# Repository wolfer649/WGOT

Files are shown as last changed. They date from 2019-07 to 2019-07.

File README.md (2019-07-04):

# World's Greatest Oven (Appliance?) Thermometer
# Overview
This is a standalone Raspberry Pi hardware assembly project and associated software that can be used to measure, chart and record appliance temperatures over time, using a cable-attached thermocouple probe.
# Features
On the the 2.8" PiTFT capacitive touchscreen, this device will show the current temperature, with the option of an additional save/hold temperature value or even a graph of the temperature over time.
The selections are chosen by pressing associated buttons on the PiTFT screen's board and by touching the PiTFT screen.

You can also reset the timer, in case you want to start recording again – say after a false start or changing adjustment values.

It also creates a csv log file that can later be used offline, to build fancy graphs or spreadsheets for analysis purposes. Two older csv log files are saved, so that data is not lost after a reboot

Optionally, this Linux-based device can be shutdown and/or restarted at the touch of a single button, to avoid having to remove and replace the power supply connection.

There is also a handy flashing LED activity indicator, so that you can check if the software is alive: especially useful in "headless" mode.

No Internet connection is required, because all of the timing is relative and typical CPU utilization is less than 10%.

For development purposes, the software can be tested on an attached X11 HDMI screen/keyboard (or via VNC) without access to the PiTFT itself, though you definitely need the Perma-Proto Hat board with the MAX31855 board attached to make it work.
# History
Proto22 was the first beta version.

Proto25 included the following changes.
- Fix the problem of the activity LED being left on after the programme exits
- Save the last two csv log files when the programme is restarted 
- Change the chart line's colour from red to blue if the current temperature is at or below freezing

Proto26 added the following changes.
- Fix the problem with the csv log file not having a time-zero entry
- Documentation was updated as well.

Proto28 added the following changes.
- Fix activity LED not being turned off after keyboard exit, via 'x' key on main display.
- Improve debug messages, if enabled in the code.
- Use Decimal arithmetic for Temperature Adjustment menu, to avoid odd values with binary math.
- Update documentation to show how to log stdout, stderr messages from rc.local.

Proto29 added the following changes.
- Shift screens to the right, to accommodate PiTFT faceplate for Cyntech case.
- Minor fixes to comments and debug code.
# Usage
Follow the instructions in the documentation to build the hardware and to install pre-requisite software.
The following command will execute the programme.
There is also an example rc.local in the documentation that will log runtime messages.

sudo python Proto29.py

or

sudo python3 Proto29.py
# Known Bugs
The activity LED may stay on after the software exits. (Proto22 - 2019-02-24)

The csv log does not include time-zero values at startup or after restart. (Proto25 - 2019-03-08)
- Fixed in Proto26

Code to force the display to the PiTFT display no longer works with Rasbian Stretch with updates if an X11 display is available.
- It still displays OK on the PiTFT when started from rc.local.
- Looking at a workaround for this issue.

Temperature Adjustment menu can show -0.0 instead of 0.0 (Proto28 - 2019-05-01)
- This doesn't cause a problem

Forcetft variable no longer forces the display to the PiTFT if an X11 display is active on Rasbian Stretch (Proto28 - 2019-05-01)
- The PiTFT display still works when it's started from rc.local, even if an HDMI X11 display is attached.
- i.e. It is still possible to run Proto28.py in headless mode, using the PiTFT as the only display.

The activity LED may stop flashing, but the PiTFT buttons still work OK. (Proto29 - 2019-07-03)
- TBD

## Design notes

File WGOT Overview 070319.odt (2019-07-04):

# World's Greatest Oven Thermometer

(Rev 0.8: Jul 3, 2019)

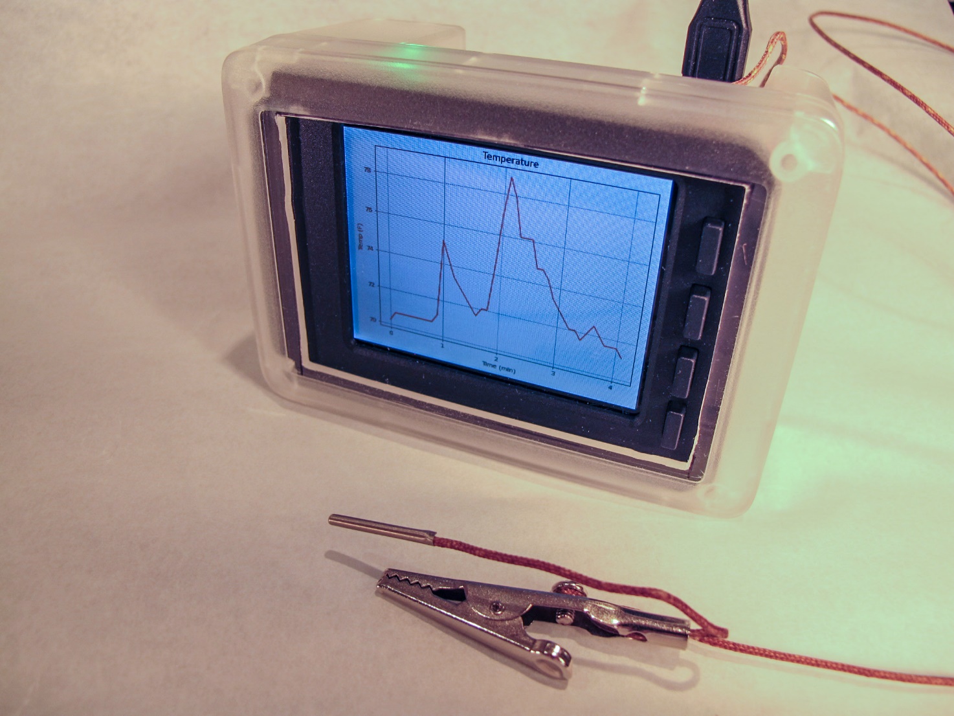
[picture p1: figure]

Note: the alligator clip is for attaching the thermocouple to an anchor point

## Features

On the the stacked 2.8" PiTFT capacitive touchscreen, this device will show the current temperature, with the option of an additional save/hold temperature value or even a graph of the temperature over time, using a cable-attached type K thermocouple probe.

The advantage of using a thermocouple is that it can measure very high and very low temperatures with good accuracy – and the Pi assembly itself doesn't have to be exposed to them.

Optionally, this Linux-based device can be shutdown and/or restarted at the touch of a single button, to avoid having to remove and replace the power supply connection.

There is also a handy flashing LED activity indicator, so that you can check if the software is alive: especially useful in "headless" mode.

No Internet connection is required, because all of the timing is relative.

It even creates a csv log file that can later be used offline, to build fancy graphs or spreadsheets for analysis purposes and typical CPU usage is below 10%. The last two csv log files are saved, so that data from a recent test isn't lost after a reboot.

For development purposes, the software can be tested on an attached X11 HDMI screen/keyboard (or via VNC) without access to the PiTFT itself, by un-commenting a single Python statement, though you definitely need the Perma-Proto Hat board with the MAX31855 board attached.

## Background

Why make an oven thermometer using a quad core, general purpose computer with a multi-user operating system? Because you can! And because of all the pieces together cost about a hundred bucks, and because all of the open source software is totally free.

When we got a new kitchen range, it didn't bake as well as the old one, so I tried a $7.99 oven thermometer – no help, since it was so very slow to respond. Then I tried a multimeter with a temperature probe, but I had to write down all of the values, over time, and graph them to a spreadsheet – too boring, time consuming and error-prone.

It was only when I cobbled together a Raspberry Pi and an Adafruit MAX31855 breakout board with a thermocouple probe, along with some copy/paste Python programming and, Matplotlib, that I uncovered the real problem. The oven's temperature was dipping down significantly from the set temperature for 10 minutes after the oven said that it was pre-heated – not good for cookies that only take 20 minutes to bake. So now we use a 20 minute pre-heat, regardless of what the oven says.

Problem solved? Well yes, except that we had friends with similar issues and it was a pain to drag my screen, keyboard, breadboard, Pi and cables over to their home and set it up.

So, in the interest of portability I built a prototype, self-contained unit that can be easily used to measure and graph oven temperatures, using a Raspberry Pi 3 B with Raspbian Stretch, an Adafruit MAX31855 thermocouple breakout board, an Adafruit 2.8" capacitive touschscreen, along with Python, Pygame and Matplotlib (amongst other open source packages.) All you'd need to carry around is the main unit and a power supply.

The following describes how it works and how it's made.

Please keep in mind that this is just a prototype, eh.

## Operation

When first powered on, the device will display a "Starting" splash screen, followed by a continuously updated time/temperature display with button labels.

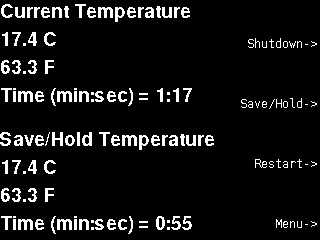
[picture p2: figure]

"Buttons" referred to below are referenced as button 1 being labelled #17 on the PiTFT board, button, 2 as #22, button 3 as #23 and button 4 as #27".

Button 1 is a software-independent OS shutdown/restart button, which will perform an orderly shutdown of the OS, when the device is active, or will reboot it if it has been shutdown. The latter saves having to disconnect and reconnect power to the Raspberry Pi to restart it after a shutdown.

The following are screenshots of the currently available display options, captured in X11 testing mode using the built-in Raspbian Stretch "scrot" command. Type "man scrot" in a terminal window to see how "scrot" works.

At any time, pressing "x" on the keyboard, or clicking "X" on the X11 window title bar will just exit the software – the current prototype debugging default.

Also, in the above display, pressing button 2 on thePiTFT (or the "h" key on the keyboard) will capture the current temperature and time as a Save/Hold Temperature and update the display.

Similarly, pressing button 3 (or "r" on the keyboard) will restart the timer and temperature capture data. A line of zero ("00") values will be written to the csv file to record this event for future analysis purposes.

Graph Display

Touching the PiTFT screen (or clicking directly on the X11 window) during the above display will switch to the following graphic display.

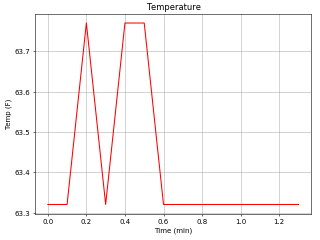
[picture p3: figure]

Axis values are automatically adjusted based on the total time period and temperature range that the graph covers, so decimal points may move or disappear and the graph line colour will change to blue if the temperature is at or below freezing.

Touching the PiTFT screen (or clicking on the window in X11 mode) while the graph is being displayed will revert to the latest active time/temperature display above.

Note that pressing button 2 (or hitting "h" on the keyboard) during the graph display will capture the current temperature and time, but will not terminate the graph display. Instead, the current time/temperature display will appear the next time the graph is touched/clicked.

Also note that the graph may appear blank after a Restart, until enough data has been recorded to show a complete graph. (i.e. After enough recording time intervals have expired.)

Menu

If you press button 4 on the PiTFT (or hit "m" on the keyboard) either display above will switch to the following main menu display. Time and temperature will still be captured during the menu display and the updated graph or temperature display will be restored when you select the Return option.

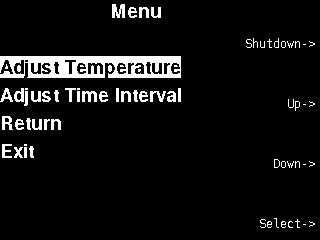
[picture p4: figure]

In menu mode, if a keyboard is available, the "u" key will simulate PiTFT button 2, to scroll the highlighting up through the options; the "d" key will simulate PiTFT button 3, to scroll down and the "s" key will simulate PiTFT button 4 to select the highlighted option. As before the "x" key, or clicking the upper-right "X" on the X11 window title bar will exit the software at any time in menu mode during testing.

The Return option will simply revert to the temperature display, while the Exit option will exit the programme completely.

Temperature Adjustment Menu

The Adjust Temperature menu allows a fixed temperature adjustment to be applied to all ongoing readings. You might use this if, for example, you notice that the temperature on the device does not match a more accurate temperature source that you have available. The value that is shown when this sub-menu appears for the first time reflects an adjustment value that is hard coded into the software.

The big assumption here is that the basic Type K thermocouple readings are linear enough within a practical usage range at home.

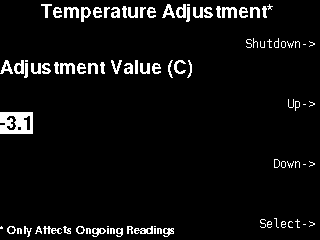
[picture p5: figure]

Up will increase the temperature adjustment by 0.1 degrees C and Down will decrease it by 0.1 degrees C within a limit of +/- 10 degrees C.

This will not affect already recorded readings - which could result in a change in the ongoing graph - until a value is Selected. In general it is a good idea to do a 'Restart' from the main temperature or graph display after making an adjustment change, to start with fresh and consistent temperature readings.

The chosen value will only take effect, once the Select button is pressed, so it is possible to undo a change by scrolling to the value that was shown when the menu initially appeared and Selecting it.

Note that adjustment value changes are not currently saved across shutdowns and so must be re-entered each time that the software is started.

Time Adjust Menu

The Time Adjustment sub-menu allows the time interval that is used for data collection (e.g. For graphing and for csv files) to be changed from a list of values that are hard-coded in the software.

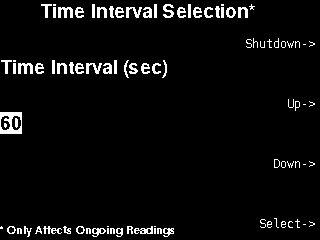
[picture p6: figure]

The chosen value will only take effect, once the Select button is pressed, so it is possible to undo a change by scrolling back to the value that was shown when the menu initially appeared. Previous data that has been recorded will not be lost unless a Restart is performed.

The list of values that is currently available is 6, 30, 60, 120, 600, 1800 and 3600 seconds, with the default being 6 seconds, so that you can watch the graph change quickly the first time you start it. The largest values may be useful for measuring things like refrigerators or outdoor temperatures.

The Up button will move through increasing values from the available values and the Down button will move through the decreasing values.

## Hardware Overview

The modestly named World's Greatest Oven Thermometer (WGOT) consists of three, stacked subassmblies.

1. A Raspberry Pi3 B bottom board
2. An Adafruit Perma-Proto Hat with MAX31855 board & connections - middle board
3. An Adafruit 2.8" PiTFT capacitive touchscreen, with buttons, on top

The following photo shows the prototype subassemblies.

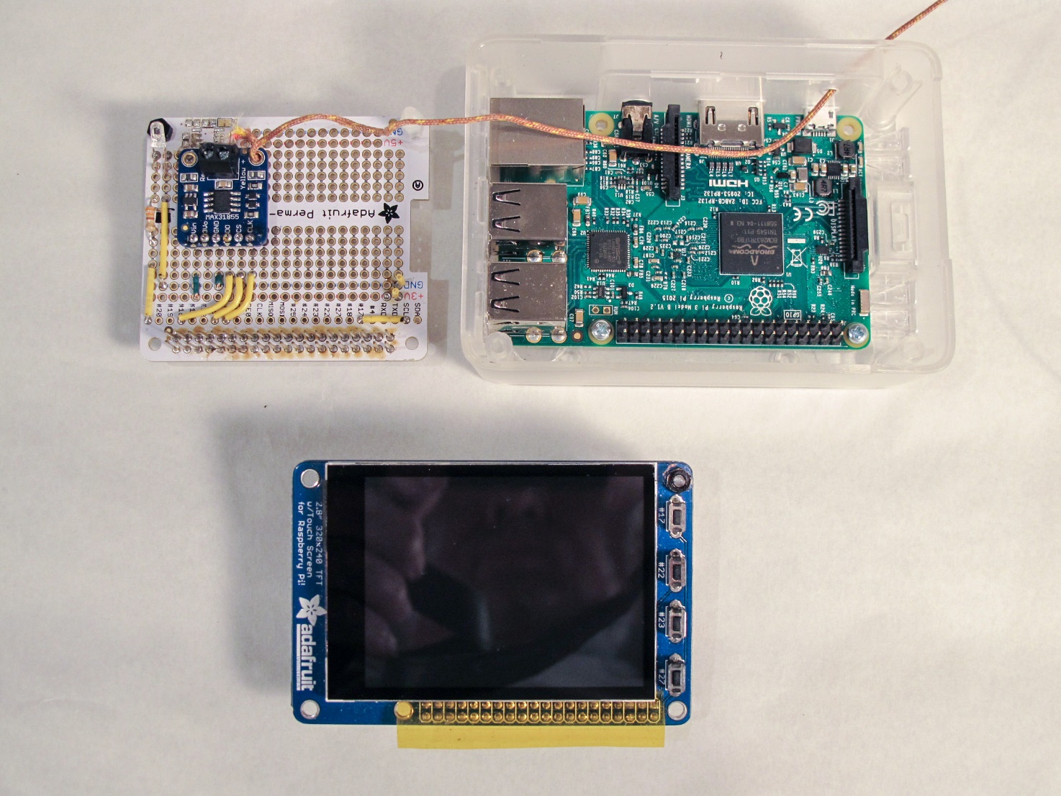
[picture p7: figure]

Note: This shows the Cyntech base case, but the Adafruit one works well for testing.

## Hardware Assembly

The following is a list of the parts required to build the prototype shown – just a starting point – using Adafruit part numbers.

Note: In Canada, most Adafruit parts and the Cyntech case are available from Elmwood Electronics - to avoid shipping delays and customs, eh.

Sub-assy | Description | Adafruit Part #
CPU
| Raspberry Pi 3 B | 3055
| Power Supply | 1995
| 32 GB micro SD card
Sensor
| Thermocouple (S/S tip) | 3245
| MAX31855 board | 269
| Perma-Proto Pi Hat (no EEPROM) | 2310
| stacking header – extra long pins | 2223
| LED, bright green
| 330 ohm Resistor, 1/4 watt, 10%
Display
| 2.8" PiTFT Cap. Touchscreen | 2423
Hardware
| M2.5 11mm normal standoffs(2) | 2336
| M2.5 16mm tall standoffs(1 of 2) | 2337
| base case - for testing (optional - see Enclosure Design below about using a Cyntech case.) | 2253

The standoffs are important, to avoid stressing the PiTFT board when pressing its buttons. The headers themselves provide support to the other side for all boards.

The following image shows the wiring for the Perma-Proto board with the MAX31855 board attached.

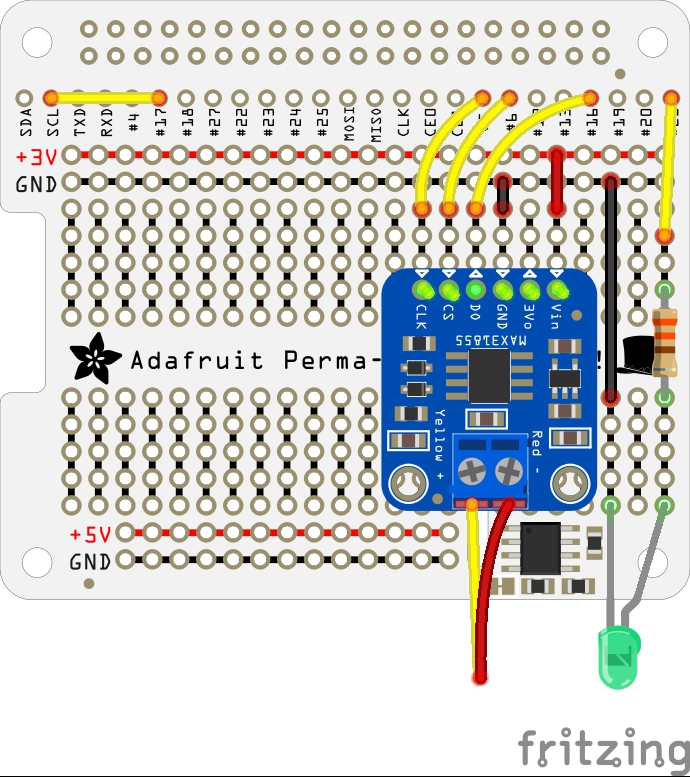
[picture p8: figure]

Note that there is enough space in the slot below the MAX31855 board through which the thermocouple wire can be routed, to provide some strain relief (instead of routing it through one of the MAX31855 mounting holes - which I did - at the cost of ripping off the shrink wrap in the process.)

One thing to note as well is that the MAX31855 board is positioned so that it does not interfere with the PiTFT board above it and so that it is far enough from the Pi CPU chip to avoid CPU heating from affecting its internal temperature calibration too much. The MAX31855 temperature output values do seem to be skewed if there is much of a temperature difference between where its chip is located and the position of the thermocouple connection. This positioning also ensures more room on the Perma-Proto board for more components, like a speaker or maybe a Bluetooth board.

The pins from the long pin header soldered to the Perma-Proto Pi Hat board extend high enough so that the 2.8" PiTFT screen can then be plugged onto them.

## Technical Details

The following table shows the GPIO usage for all of the hardware components, using BCM numbering and not Raspberry Pi pin numbers.

Device | GPIO# | Usage | Notes
2.8" PiTFT Screen | | | Adafruit #2423
| 2 | SDA | I2C
| 3 | SCL | I2C + power on (short to GPIO 17)
| 8 | CE0 | SPI0
| 9 | MISO | SPI0
| 10 | MOSI | SPI0
| 11 | SCLK | SPI0
| 17 | Button 1 | Top button = power off
| 22 | Button 2
| 23 | Button 3
| 24 | PiTFT
| 25 | PiTFT
| 27 | Button 4 | Bottom button
MAX31855 Board | | | S/W SPI
| 5 | | CLK
| 6 | | CS
| 16 | | DO
Activity LED | 21 | GPIO.OUT | SPI1 SCLK
Reserved-ish
| 7 | CE1 | HAT ID?
| 18 | PWM0 | Used for headphone jack?
Free-ish
| 0 | ID_SD
| 1 | ID_SC
| 4 | GPCLK0
| 12 | PWM0
| 13 | PWM1
| 14 | TXD
| 15 | RXD
| 19 | MISO
| 20 | MOSI
| 26

## Pre-requisite Software Package Installation

The nice thing about open source software is that it's all free. Unfortunately, this also means that various packages change so fast over time that any development effort is out of date by the time that it is released – probably like for this one. This software is (now) based on Python 3 though it works with Python 2, so your mileage may vary.

e.g. Current pygame SDL support for TSLIB touchscreens in Stretch means that we can only detect touchscreen events, but the positition information and other TSLIB filtering are lost.

In this document, what is described below is based on Raspbian Stretch, 2018-06-27, so you may not experience the same results at home. (e.g. I am still having issues with Raspbian Stretch 2018-11-13 to force the display to the PiTFT.)

The following is what I did.

In addition to installing the full version of Raspbian Stretch, the following software packages need to be installed.

- Adafruit MAX31855 support
- Adafruit PiTFT support
- Matplotlib for Python

All other packages, like Pygame or RPi.GPIO are included in Stretch or derived from the above.

Adafruit MAX31855 Support

To install the Adafruit MAX31855 support, go to the following link to download and install it, following all of the instruction steps.

https://learn.adafruit.com/max31855-thermocouple-python-library/software

If you are planning to use Python 3, it might still be necessary to use the following commands to install the MAX31855 libraries for it, in case you get "import" errors, because Python 2 is/was the current default for the 'python' command with Stretch as of this writing.

cd ~/Adafruit_Python_MAX31855

sudo python3 setup.py install

Adafruit 2423 2.8" Capacitive Touchscreen Support

To install the Adafruit 2.8" Capacitive touchscreen support, go to the following link and use the Easy Install process provided. Watch for any errors and follow any advice provided if they occur.

https://learn.adafruit.com/adafruit-2-8-pitft-capacitive-touch/easy-install-2

Select your PiTFT device (3 for the PiTFT Capacitive Touchscreen, choose rotation option 1 (landscape) and then say "no" to the the next two configuration questions – so that the PiTFT can be used as a separate framebuffer device from the normal X11 console.

It also is a good idea to make sure that the PiTFT works as /dev/fb1 by following the instructions at the following link.

https://learn.adafruit.com/adafruit-2-8-pitft-capacitive-touch/displaying-images

Note: Swiping the PiTFT screen while in X11 testing mode can cause unpredictable results on the X11 screen, even when the software is not running. So be careful if you want to clean it!

Matplotib

To install Matplotlib, go to the following link and follow the instructions for Linux.

https://matplotlib.org/users/installing.html

Be sure to use the apt-install process for Debian instead of the pip-install process that shows up first.

e.g. As of this writing, use the following command.

sudo apt-get install python3-matplotlib

You can also try the following command on your Raspberry Pi if you are going to use Python 2.

sudo apt-get install python-matplotlib

Other Packages

You may also want to enable VNC – already installed in Stretch - on your Pi, if you want to do remote development as well as to easily transfer files. Also, if you want to print from your Pi, you can install CUPS, though you'll likely have to figure out the closest printer that matches what you actually have.

## OS Customization

There are two main OS customizations that are required for this project, if you want to use their associated features. These should be done after all pre-requisite software packages are installed.

1. Update /boot/config.txt so that PiTFT button 1 (labelled #17) will cause a shutdown.
2. Update /etc/rc.local so that the software is started at boot time – e.g. for "headless" mode.

Shutdown/Restart Button

To use button 1 on the PiTFT as an OS shutdown button, add the following lines to end of the /boot/config.txt file using, say, "sudo nano /boot/config.txt". Ideally, updates from the PiTFT display install should appear at the bottom of the file if you've used the Adafruit Easy Install script for the PiTFT already, which you should have done previously.

# --- Added for WGOT project

# --- Make GPIO 17 (button 1 on PiTFT 2.8") shutdown when pressed

dtoverlay=gpio-shutdown,gpio_pin=17

# --- end WGOT project updates

Note that using button 1 to restart after shutdown is accomplished by connecting GPIO 17 to GPIO 3 on the Proto-Perma PiHat board. (This is OK, because the GPIO 3 I2C SCL pin can be pulled to ground – part of the I2C protocol.)

Auto Start at boot

When you are done testing and want to run the fully assembled device in headless mode, you need to update /etc/rc.local to automatically start the WGOT software.

Add the following lines to the end of rc.local, but before the "exit 0" statement using, say "sudo nano /etc/rc.local".

# Start WGOT Python program in separate process

sudo python /home/pi/Proto29.py &

Note that the above contains the full path name for the file that I used. Yours may be different, but it must be the full path name for the file. Also, the "&" is very important, to ensure that the progamme is started as a separate process and does not hold up the rest of the OS startup process.

Alternatively, if you want to log messages from stdout and stderr to shifting log files – so you don't lose the log data over reboots - you can try this version of /etc/rc.local.

#!/bin/sh

# rc.local

# This script is executed at the end of each multiuser runlevel.

# Make sure that the script will "exit 0" on success or any other

# value on error.

# In order to enable or disable this script just change the execution

# bits.

# By default this script does nothing.

# Print the IP address

_IP=$(hostname -I) || true

if [ "$_IP" ]; then

printf "My IP address is %s\n" "$_IP"

fi

# Shift WGOT log files, ignoring errors (ie no -e flag on the first line above)

# Target directory must be enabled for 'write' for 'others'

rm /home/pi/WGOTlog2.txt

mv /home/pi/WGOTlog1.txt /home/pi/WGOTlog2.txt

mv /home/pi/WGOTlog.txt /home/pi/WGOTlog1.txt

# Start WGOT Python program in separate process and log msgs

# The final ampersand makes it start in a separate process,

# so rc.local can complete

sudo python /home/pi/Proto29.py >/home/pi/WGOTlog.txt 2>&1 &

exit 0

For the example above, which uses /home/pi to hold log files, you first have to let rc.local, which runs as root, to write to the home/pi directory - e.g. using the following overly permissive command.

chmod 777 /home/pi

If you have made a terrible decision to go headless and the software bombs, it is not the end of the world. You can always reconnect your HDMI monitor and keyboard and restart the Pi, so that you can update /etc/rc.local to comment-out the auto-start command while you fix the problem.

## Software Overview

The software is heavily commented, because it might make it easier to understand. Though not pretty, the software might also suggest some answers about Python, Pygame, Matplotlib, SDL, PiTFT and other questions for which I couldn't always find useful answers on various forums.

## Software Testing/Debugging

The software currently offers some testing variables that are defined near the top of the code for ease of access.

1. Forcetft, which if set to True might force the display to the PiTFT, when started from an X11 window. If set to False, it will allow SDL to choose the display target – usually a window on an X11 display. (Doesn't work with Stretch 2018-11-13 as of this writing.)
2. Debugprt, which if set True will print some debugging info, for testing purposes or, if set to False, will supress these messages. There are also some debug print lines that are commented out, because they are annoying – except for very detailed debugging.
3. Glitchless, which if set True will smooth out some of the one time temperature glitches I kept experiencing.
4. Tempadj, which is a fixed +/- Celsius temperature value to be added to the readings from the MAX31855 based on your calibration testing.
5. Csvfilename, which is the full path name for the file to hold recorded values in csv format.
  - This is set to '/home/pi/WGOTdata.csv'
  - Saved csv files use the name above with save1 or save2 appended to the name.
6. Graphfile, which is the full path name for a temporary file to hold graphs.
  - This is set to 'home/pi/WGOTgraph.png'

First try the following command to see what happened when rc.local was run.

systemctl status rc.local.service

In addition, if the software is started in headless mode and something goes wrong, you can try looking at the following verbose sources for error messages.

/var/log/boot.log

/var/log/messsages

/var/log/daemon.log

You can also modify the commands in /etc/rc.local to direct stdprint and stderr output to a log file of your choosing, as shown in the example above.

## Enclosure Design

The following example is for those who would like a neat, self-contained enclosure, but with a minimum of mechanical skills, unlike, say, Ben Heck.

It consists of a Cyntech Raspberry Pi case, - with a spacer to accomodate the extra height of the Perma-Proto Hat – and a modified Adafruit PiTFT faceplate with buttons (Adafruit #2807), sandwiched between the cap and the PiTFT. There is also a handy hole on the side of the Cyntech case for the thermocouple cable to exit the case. I also chose the clear Cyntech case so that the activity LED would be visible from above – reflected through the case itself.

I also passed the thermocouple probe through an alligator clip, so that I could attach it to an oven grill or fridge grill.

The following diagram shows how the unmodified Cyntech case works – copied from the Cyntech web site.

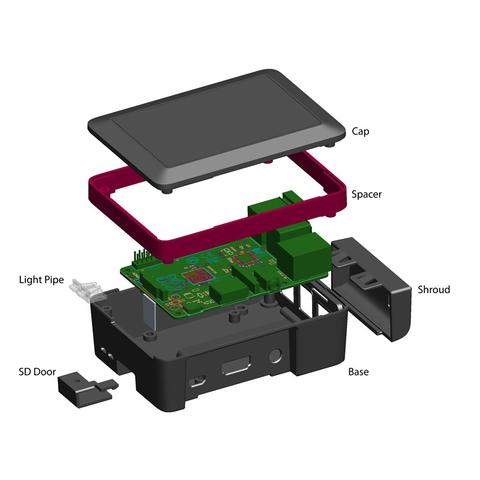
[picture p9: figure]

Modification to the Cyntech case requires milling out the shiny part of the cap to expose the screen and buttons of the Adafruit PiTFT faceplate that will go just below it. I used a Dremel tool and a file to do this part.

Modification to the Adafruit PiTFT faceplate requires cutting out the corners on the long side of the faceplate to clear the screw holes for the Cyntech case, as well as bevelling both ends to better mesh with the Cyntech cap – it's a tight fit. Once again, I used a Dremel tool and a file, though a fine saw and a file might be better.

In addition the top of the M2.5 16mm standoff that supports the upper right corner of the PiTFT display needs to be filed down to the top of the nut that holds it on for clearence purposes. Using an equivalent nylon standoff makes this job easier, since you can just clip off most of the extra length.

The image below shows the modified components used for the final enclosure, less buttons and screws.

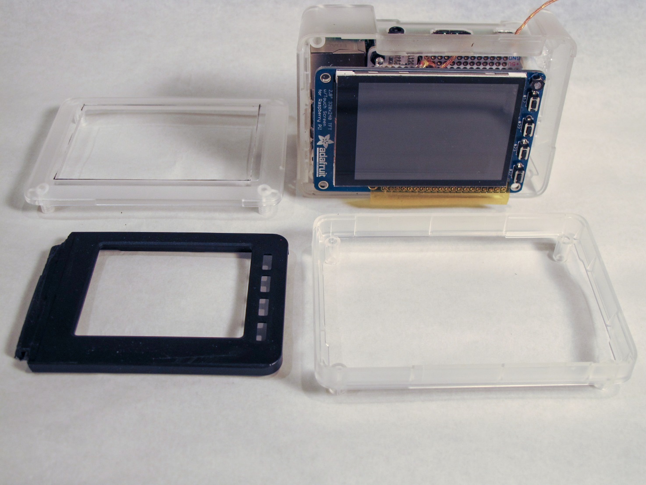
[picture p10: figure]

Note that is best not to tighten the assembly screws too much or the buttons on the faceplate may not have enough space to move properly.

The final enclosure assembly is show in the following picture.

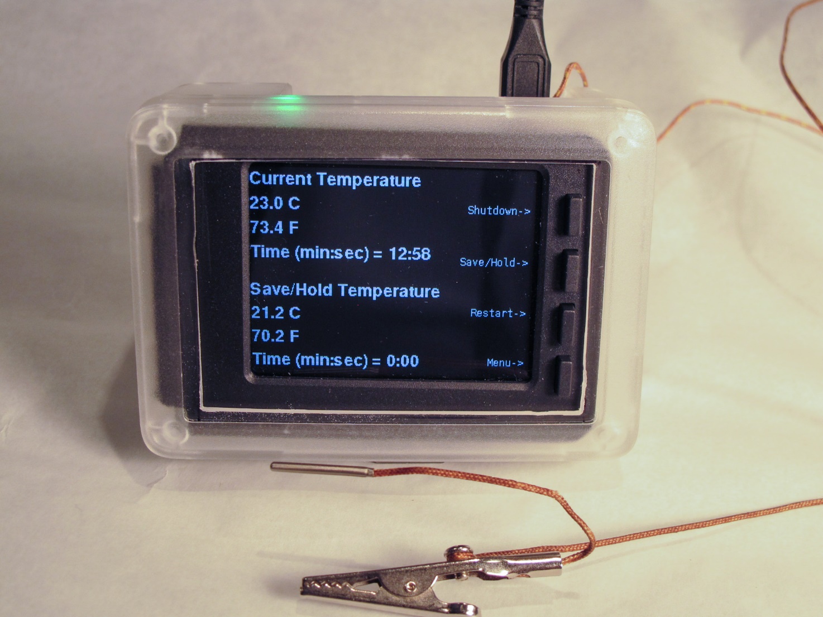
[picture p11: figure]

Note: The green “Activity LED” (shown on) flashes on and off once per second while the software is running.

## Future Improvements

So, what's not to like?

Well, there could be just a few improvements - such as the following – in the fullness of time.

- Change the name. (to World's Greatest Appliance Thermometer – WGAT. :-)
- Accept command line arguments for some variables.
- Save the time and temperature adjustment values over shutdowns.
- Save csv log data to a USB memory key.
- Add more menus for setting things, like C vs. F display/graph, saving to USB, smoothing, etc.
- Build a more general purpose menu tree driver without making the code any harder to read.
- Figure out the glitchy temperature readings.
- Better debugging tools, cleaner, easier to read code, etc.
- Much, much more.

In the interest of sharing, and before the software balloons too large to comprehend, I am publishing this prototype version.so that newbies like me may benefit from some of the lessons I've learned.

A Big Thank You to Adafruit & friends for their products, software, documentation, tutorials and forums! As a newbie to Python, Pygame, etc., this wouldn't exist otherwise.

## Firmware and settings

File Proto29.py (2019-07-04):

#!/usr/bin/python
# Copyright (c) 2014 Adafruit Industries, 2019 R.S. Fowler
# Author: Tony DiCola - for content from simpletest.py
# Author: R.S. Fowler for WG Oven Thermometer project
#
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
# Can enable debug output by uncommenting:
#import logging
#logging.basicConfig(level=logging.DEBUG)
# ---- End of Adafruit disclaimer - RSF too

# -----Define testing variables - up front for ease of access.
Forcetft = True # if False, SDL will try X11 first. If True, the PiTFT will be forced.
Debugprt = True # if True, some debug printing will be enabled
Tempadj = -3.0 # Fixed temperature adjustment in C - from calibration testing
Glitchless = False # Cheat - if True, one time temp differences will be removed
# The following should really be made arguments for the command line
Csvfilename = '/home/pi/WGOTdata.csv'
Graphfile = '/home/pi/WGOTgraph.png'
# -----End testing variables

# -----Define some colour tuple names for shorthand use
BLACK = (0,0,0)
WHITE = (255, 255, 255)
RED = (255, 0, 0)
GREEN = (0, 255, 0)
BLUE = (0, 0, 255)

########################################
# ----- Menu/Screen Definitions
########################################

# Each dictionary describes a screen format
# Each dictionary key is a relative line value - they could be on the same physical line
# Each dictionary value item is a list for that line
# {line_value: [line_position, textsize, indent, font, text]}
# where:
# - line_value is a unique line number
# - line_position is the position of the line from the top of the screen in pixels*textsize
# - textsize is the text height in pixels
# - indent is the left indentation in pixels
# - font is an available Sysfont name in quotes or None
# - Text is the text to be shown, in quotes
# Values can be updated by the code before showing the screen

# Define a basic Splash screen
splash_screen = {
    0:[3, 30, 120, None, 'Starting ...']}

# Define the Temperature(s) screen for normal mode
# Note: Text indent of 4 below is to clear the bezel edge
temp_screen = {
    0: [0, 28, 4, None, 'Current Temperature'],
    1: [1, 28, 4, None, '60.9 C'],
    2: [2, 28, 4, None, '69.5 F'],
    3: [3, 28, 4, None, 'Time (min:sec) = mm.ss'],
    4: [4.6, 28, 4, None, 'Save/Hold Temperature'],
    5: [5.6 ,28, 4, None, '20.1 C'],
    6: [6.6, 28, 4, None, '10.7 F'],
    7: [7.6, 28, 4, None, 'Time (min:sec) = mmm.ss']}

# Define the main menu for menu mode
main_menu = {
    0: [0, 28, 110, None, 'Menu'],
    1: [2, 28, 4, None, 'Adjust Temperature'],
    2: [3, 28, 4, None, 'Adjust Time Interval'],    
    3: [4, 28, 4, None, 'Return'],
    4: [5, 28, 4, None, 'Exit']}
Mmenumax = 4 # maximum number of selectable lines on main menu (1 thru 4)

# Define the Temperature Adjustment menu for menu mode
tempadj_menu = {
    0: [0, 28, 40, None, 'Temperature Adjustment*'],
    1: [2, 28, 4, None, 'Adjustment Value (C)'],
    2: [4, 28, 4, None, '0.0'], # a dummy placeholder
    3: [14, 16, 4, None, '* Only Affects Ongoing Readings']}

# Define Time Interval Selection menu for menu mode
timeadj_menu = {
    0: [0, 28, 40, None, 'Time Interval Selection*'],
    1: [2, 28, 4, None, 'Time Interval (sec)'],
    2: [4, 28, 4, None, '6'], # a dummy placeholder
    3: [14, 16, 4, None, '* Only Affects Ongoing Readings']}
# Matching time adjust values for the above menu, in seconds
Timevals = [6, 30, 60, 120, 600, 1800, 3600]

# Define button labels dictionary to go with the tempatures screen
# (right alignment is hard, hence the leading blanks and mono-spaced font)
button_menu1 = {
    0: [3, 12, 240, 'DejavuSansMono', ' Shutdown->'],
    1: [8, 12, 240, 'DejavuSansMono', 'Save/Hold->'],
    2: [13, 12, 240, 'DejavuSansMono', '  Restart->'],
    3: [18, 12, 240, 'DejavuSansMono', '     Menu->']}

# Define button labels dictionary for menu mode
button_menu2 = {
    0: [3, 12, 245, 'DejavuSansMono', 'Shutdown->'],
    1: [8, 12, 245, 'DejavuSansMono', '      Up->'],
    2: [13, 12, 245, 'DejavuSansMono', '    Down->'],
    3: [18, 12, 245, 'DejavuSansMono', '  Select->']}


########################################
# ----- Import all required packages
########################################
# Note: all packages except MAX31855 and Matplotlib are part of Raspian Stretch

import time
import os # used to update environment variables
import sys # used to exit and to get command line arguments
import getopt # used to parse command line arguments
from decimal import Decimal # needed to do correct temperature adjustment
import pygame # used to manage the display contents and timers
from pygame.locals import *
from pygame import event, fastevent # fastevent is for multithreaded posts
import RPi.GPIO as GPIO # GPIO is a shorthand name
# The following require prior s/w installations.
# Follow the directions on the back of the box for details.
import Adafruit_GPIO.SPI as SPI # From Adafruit MAX31855 package
import Adafruit_MAX31855.MAX31855 as MAX31855 # to talk to the MAX31855 board
import matplotlib # used to make graphs
# the following line allows this program to start from rc.local to avoid errors
matplotlib.use('Agg') # Needed to run screenless matplotlib - BEFORE importing pyplot
import matplotlib.pyplot as plt # plt is a shorthand name for Python Matplotlib
import numpy as np # np is a shorthand name

########################################
#----- Function Definitions
########################################

# --Define a function to turn GPIO PiTFT button events into Pygame events using fastevent
# Note: This function runs in a separate thread from the main programme.
# Note: using pygame.event.post causes "video system not initialized" error
#  so we use fastevent.post, based on (very terse) pygame doc.
def gpiobut(channel): # 'channel' is PiTFT button's BCM GPIO value for GPIO event
# post pygame event based on PiTFT button pushed
    if channel == 22: # using literals for clarity. e.g. GPIO 22 is button 2
        fastevent.post(pygame.event.Event(pygame.USEREVENT+3, button=2)) # use fastevent for separate thread pygame post
    elif channel == 23: # check for button 3
        fastevent.post(pygame.event.Event(pygame.USEREVENT+3, button=3))
    elif channel == 27: # check for button 4
        fastevent.post(pygame.event.Event(pygame.USEREVENT+3, button=4))
# ignore anything else
#--End gpiobut callback function

# --Define a function to convert Celsius to Fahrenheit.
def c_to_f(c):
    return c * 9.0 / 5.0 + 32.0
# -- End c_to_f function
    
# --Define a function to get the temperature from the MAX31855 board
def get_temp():
# Get the external probe and internal chip temperatures in Celsius
    tempc = sensor.readTempC() + Tempadj # get the termperature and adjust for calibration
    itempc = sensor.readInternalC() # Debug
#    if Debugprt == True:
#        print ('Ctemp=',tempc, 'Itemp=',itempc) # track results against observed
    return tempc; # Return the temperature in Celsius only, for now
# --End get_temp function
    
# --Define  a function to plot a graph to a file
def make_graph(): 
#    if Debugprt == True: # print the timing in debug mode        
#        print (pygame.time.get_ticks()/1000,Timex, 'make_graph start') #debug
    fig, ax = plt.subplots() # define the
    fig.subplots_adjust(left=0.11, right=0.97, top=0.94, bottom=0.11) # reduce margin size
    if Curtemp > 0: # check if current temperature is above freezing
        ax.plot(Timelist, Templist, 'red') # if so, plot the graph in red
    else: # for temperatures at or below freezing
        ax.plot(Timelist, Templist, 'blue') # if so, plot the graph in blue        
    ax.set(xlabel='Time (min)', ylabel='Temp (F)',title='Temperature') # add axis labels
    ax.grid() #show with default grid for major axes
# The following creates a 320 x 240 pixel (for now) graph image file
#   after experimenting with 'dpi' values.
    fig.savefig(Graphfile, bbox="tight", dpi=50.1) # save graph
    plt.close('all') # free up memory from graph creation
#    if Debugprt == True: # print the timing in debug mode        
#        print (pygame.time.get_ticks()/1000,Timex, 'make_graph end') #debug
# --End make_graph function

# --Define a function to show a graph from a file onto the screen
def show_graph():
# Will show the graph on the PiTFT (or X11) with PyGame
# Show an image (320x240) - created previously by matplotlib
    Lcd.fill (BLACK) # Blank the display  
    graph = pygame.image.load(Graphfile)
    Lcd.blit(graph, (0,0)) # place in upper left corner
    pygame.display.update() # Show it
# --End show graph function

# --Define a function to show a screen of text with button labels
# Note: text items in the screen dictionary can be changed before displaying
def show_text_menu(menuname, highlite, buttons): # buttons can be None
    Lcd.fill(BLACK) # blank the display
# Build button labels first, so menu can overlap on leading blanks
    if buttons != None: # see if there are buttons to show
        line = 0 # reset our line count for the labels
        for line in buttons: # go through the  button line vslues
            linedata = buttons[line]
            myfont = pygame.font.SysFont(linedata[3], linedata[1]) # use the font selected        
            textsurface = myfont.render(linedata[4], False,WHITE,BLACK) # write the text
            Lcd.blit(textsurface,(linedata[2],linedata[1]*linedata[0])) # show the text
            line = line + 1 # go to the next line    
# Build the rest of the menu
    line = 0 # start showing at line zero
    for line in menuname: # go through the line values
        linedata = menuname[line] # get the value list from the menu dictionary
        myfont = pygame.font.SysFont(linedata[3], linedata[1]) # use the font selected
# Build text and position & highlighting a line, if within range
        if line == highlite: # check if we should highlight this line
            textsurface = myfont.render(linedata[4], False, BLACK,WHITE) # highlight it
        else:
            textsurface = myfont.render(linedata[4], False, WHITE,BLACK)  # no highlight           
        Lcd.blit(textsurface,(linedata[2],linedata[1]*linedata[0])) # add the line to the screen        
        line=line+1
# Show the new screen
    pygame.display.update() # show it all
# --End show_text_menu function

# --Define a function to show the temperatures/times in text
def show_temp(): # shows hold temperatures too
#    if Debugprt == True: # print the event in debug mode
#        print ('show_temp', Updtimex, Updinterval, Minx, Secx) #debug 
    Lcd.fill (BLACK) # blank the display
    curtemp = get_temp() # get the current temperature in a local variable
    tempf = c_to_f(curtemp) #calulate temperature in F
# Update the dictionary for this screen with new temperature/time values
# Each line updates the text element[4] in the associated dictionary line's value list
    temp_screen[1][4] = str.format("%.1f" % curtemp +" C") # change the text, 4 in the list
    temp_screen[2][4] = str.format("%.1f" % tempf +" F") # update menu text in dictionary
    temp_screen[3][4] = str.format("Time (min:sec) = "+str(Minx)+":"+str(Secx).zfill(2)) # change the text content
# Update Hold values too
    temp_screen[5][4] = str.format("%.1f" % Htemp +" C") # change the text content
    temp_screen[6][4] = str.format("%.1f" % Htempf +" F") # change the text content
    temp_screen[7][4] = str.format("Time (min:sec) = "+str(Hminx)+":"+str(Hsecx).zfill(2)) # change the text content
    show_text_menu(temp_screen, None, button_menu1) # Put it on the screen
# --End show_temp function

# --Define a function to flip between temperature and graph displays
def show_flip():       
    global Displayshow # make this global
    if Displayshow == Displaytemp: # if showing the temps, 
        Displayshow = Displaygraph # switch to showing a graph
        make_graph() # get a current graph right now
        show_graph() # put it on the screen
    else: # otherwise,
        Displayshow = Displaytemp # switch to showing temps
        show_temp() # show the temps right now
# ---- End show_flip function

# --Define a function to do time/temp display updates on a timer 2 pop
# Note: this only affects the temperature/time display and activity LED
def Do_ttimer_updates(): # 
    global Led, Updtimex, Minx, Secx # declare globals as needed
# Perform common timer 2 pop updates
    Updtimex=Updtimex + Updinterval # update increment to seconds
    Minx = Updtimex // 60 # get elapsed time in minutes
    Secx = Updtimex % 60 # get remainder secs elapsed
# Toggle a basic LED activity indicator, since this timer never changes
    if Led == True: # check if the LED is on
        GPIO.output(Ledgpio, GPIO.LOW) # if so, then turn it off
        Led = False # record that it is off
    else:
        GPIO.output(Ledgpio,GPIO.HIGH) # otherwise, turn on the LED
        Led = True # record that it is on           
# --End of ttimer_updates updates function for timer 2
    
# --Define a function to perform common timer 1 pop updates for all modes
# Note: this affects data saving/recording and graphs
def Do_rectimer_updates():
    global Timex, Minx, Secx, Curtemp # declare global variables required    
# Perform common timer 1 pop updates
    Timex = Timex + Tinterval # update increment in seconds
    Curtemp=get_temp() # get current temp
    Templist.append(c_to_f(Curtemp)) # add to list
    Timelist.append(Timex/60.0) # add the new value, but in mintes
# Filter out one-time temperature glitches - works only in steady state for now.
# This is a cheat for cosmetic purpose for now. Still get bumpy graphs.
    if Glitchless == True and len(Templist) >2: # see if we want to reduce temp glitches
        if Templist[-3] == Templist[-1] and Templist[-2] != Templist[-1]: # chk glitch
            Templist[-2]=Templist[-1] # smooth over the glitch
# Write data to log
    Csvlog.write("{0},{1},{2}\n".format(str(int(Timex)),str(Curtemp),str(c_to_f(Curtemp)))) # write time (sec) and temp (F)
    Csvlog.flush() # make sure the file is updated immediately     
# --End of Do_rectimer_updates function    

#---------------End Function Definitions-----------
########################################
#----- Begin Main Programme
########################################
#---------------Initialization---------------------

# --Initialize the PiTFT LCD and touchscreen

LCD_WIDTH = 320 # the width of the PiTFT in pixels
LCD_HEIGHT = 240 # the height of the PiTFT in pixels
LCD_SIZE = (LCD_WIDTH, LCD_HEIGHT) # make it into a tuple for later
# Setup SDL system variables to use the PiTFT
os.putenv('SDL_FBDEV', '/dev/fb1') # specify device as frame buffer1
os.putenv('SDL_MOUSEDRV', 'TSLIB') # TSLIB doesn't work too well with Stretch
os.putenv('SDL_MOUSEDEV', '/dev/input/touchscreen') # Mouse is PiTFT touchscreen
# The following checks whether to take the SDL default screen (usually X11) or not
# Note: HDMI (X11) display will blank during this test on an actual PiTFT
if Forcetft == True: # See if we want to force using the PiTFT
#    os.environ['SDL_VIDEODRIVER'] = 'fbcon' #test
    os.putenv('SDL_VIDEODRIVER','fbcon') # force PyGame display to the PiTFT, maybe
# --End PiTFT Initialization

# --Intialize MAX31855 configuration - from Adafruit sample code
# Must run as Root (sudo) for this to work
# Raspberry Pi software SPI configuration
CLK = 5 # RSF - was 25 - avoid piTFT conflict
CS  = 6 # RSF - was 24 - avoid piTFT conflict
DO  = 16 # RSF - was 18 - avoid potential piTFT or PWM conflict
sensor = MAX31855.MAX31855(CLK, CS, DO)
# --End MAX31855 initialization

# --Initialize Pygame
pygame.init() #Initialize Pygame
pygame.mouse.set_visible(False) # Hide the useless mouse pointer   
Lcd = pygame.display.set_mode(LCD_SIZE) # Create a pyame 'display surface' all we'll need
fastevent.init() # Initialize fastevents for multithreaded GPIO detect
pygame.event.set_blocked(pygame.MOUSEMOTION) # Block these from filling the event queue
pygame.event.set_blocked(pygame.MOUSEBUTTONUP) # Block these from filling the event queue too
pygame.font.init() # Required to use fonts

# -Initialize pygame timer events
# Initialize the pygame time event and variables for recording purposes
Timeval = 0 # start sample rate at first entry in list
Tinterval = Timevals[Timeval] # set the timer interval in msec
# Define  a pygame user event for the recording timer
pygame.time.set_timer(USEREVENT+1, Tinterval*1000) # create a timer event #1

# -Initialize a pygame timer event to update the time/temperature display
Updinterval = 1 # Update interval in sec (may be longer for easier save/hold)
Updtimex = 0 # Initialize update timer value since start
pygame.time.set_timer(USEREVENT+2, Updinterval*1000) # create timer event #2
# --End Pygame initialization

# --Show a splash screen during initialization, in case it takes some time to start
show_text_menu(splash_screen,None,None) # Show the splash screen - no buttons
# --End show splash screen

# --Initialize GPIO for PiTFT 2.8" touchscreen P/N 2423 buttons and activity LED
# Note: PiTFT buttons connect GPIO port to ground, hence pull them up when open
GPIO.setmode(GPIO.BCM) # use BCM chip's numbering scheme vs. pin numbers
# Note: Button 17 (top right) is assumed reserved for OS shutdown here
#  by configuring it in /boot/config.txt with dtoverlay=gpio-shutdown,gpio_pin=17
# Wiring it directly to GPIO 3 also makes it an OS revive button
GPIO.setup(22, GPIO.IN, pull_up_down=GPIO.PUD_UP) #PiTFT button 2
GPIO.setup(23, GPIO.IN, pull_up_down=GPIO.PUD_UP) #PiTFT button 3
GPIO.setup(27, GPIO.IN, pull_up_down=GPIO.PUD_UP) #PiTFT button 4
Ledgpio = 21 # pick a free GPIO for the activity LED, handy location on PiHat too
GPIO.setup(Ledgpio, GPIO.OUT) # Define a pin for simple LED activity indicator
GPIO.output(Ledgpio, GPIO.HIGH) # turn on the LED to show we're running
Led = True # record the state of the LED
# Define GPIO button event handlers for the PiTFT 2423
GPIO.add_event_detect(22, GPIO.FALLING, callback=gpiobut, bouncetime=300)
GPIO.add_event_detect(23, GPIO.FALLING, callback=gpiobut, bouncetime=300)
GPIO.add_event_detect(27, GPIO.FALLING, callback=gpiobut, bouncetime=300)
# --End GPIO Initialization

# --Initialize main variables
Timex=0 # total time since execution started in seconds
Minx=0 # total time since execution started in minutes
Secx=0 # leftover seconds for Minx:Secx display
Ttempadj = Tempadj # Set temporary timer interval to the same, for Time Adj menu
Curtemp=get_temp() # get current temperature to start
Timelist=[Timex/60.0] # dummy list for make_graph
Templist=[c_to_f(Curtemp)] # dummy list for make_graph
Displaytemp=1 # value if we're showing temperature
Displaygraph=2 # value if we're showing a graph
Displayshow=Displaytemp # default to show temperature initially
Htemp = Curtemp # Initialize Hold data as well
Htempf = c_to_f(Curtemp)
Htimex = 0 # init hold time
Hminx = 0 # init hold time min
Hsecx = 0 # init hold time sec
Mousetimer = pygame.time.get_ticks()/1000 # init timer (sec) for mouse/touch debounce
Mousewait = 2 # choose 2 sec between MOUSEDOWN events for touch debounce
Menumode = False # Start without a menu
Mmenuline = 1 # start with line 1 on main menu
# --End main variables initialization

# --Intitialize a csv-format log file and save two previous ones
# - Try to save some csv file to avoid data loss over reboot/restarts
try: # only if it exists, remove the oldest save file
    os.remove(Csvfilename+'save2') # remove oldest (save2) file first
except: # if it's not there, we don't care
    pass
try: # only if it exists, rename the old save file to oldest
    os.rename(Csvfilename+'save1',Csvfilename+'save2') # rename save1 to save2
except: # if it's not there, we don't care
    pass
try: # only if it exists rename the last  csv log file to save1
    os.rename(Csvfilename,Csvfilename+'save1') # rename the last to save1
except: # if it's not there, we don't care
    pass
# - Open the new file, regardless of what happened just above   
Csvlog = open(Csvfilename,"w") # open the csv log file fresh, for writing
Csvlog.write("{0},{1},{2}\n".format(str(int(Timex)),str(Curtemp),str(c_to_f(Curtemp)))) # write time (sec) and temp (F)
Csvlog.flush() # make sure the file is updated immediately 
# --End csv log file initialization

#------------End Initialization----------------

################################################
# ----- Main code event loops - there are two:
# ------  One for non-menu mode and one for menu mode
################################################
while True: # loop forever, waiting for events in any mode

########################################
# ----- Handle events in non-menu mode
########################################
    while Menumode == False: # loops waiting for events in 'normal' mode
        event = pygame.fastevent.wait() # wait for an event object to check
#        if Debugprt == True: # print the event in debug mode
#            print (pygame.time.get_ticks()/1000,Timex, event, "normal mode") # annoying debug

# --Handle Quit if window is closed  - in X11 display mode only
        if event.type == QUIT: # only works in an X11 window or shutdown
            if Debugprt == True:
                print ("Quit Selected")
            Csvlog.close() # close the csv log file
            pygame.display.quit() # clean up
            GPIO.output(Ledgpio, GPIO.LOW) # turn off the LED
            sys.exit() # exit this programme
# -- End of Quit event handler            

# --Handle the recording timer pop 1 event           
        elif event.type == pygame.USEREVENT+1: # using literal here for timer pop 1
            Do_rectimer_updates() # update variables and log
# Show graph, if that's the mode we're in           
            if Displayshow == Displaygraph: # show a graph, if required
                 make_graph() # build the graph
                 show_graph() # show the graph
# -- End of timer pop 1 event handling
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

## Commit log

2019-02-25 World's Greatest Oven Thermometer
    A Raspberry Pi-based appliance thermometer project that can show
    temperatures and times in text or graphical format on a small TFT
    touchscreen in a single hardware assembly. Features include csv file
    recording of data, an activity LED and menus to adjust time recording
    and temperature values.
2019-03-15 Fritzing file for middle board
    [midboard sketch 031319a.fzz]
2019-03-15 Updated documentation
    Now includes Fritzing image for middle board
2019-07-04 Updated to accommodate Cyntech case enclosure
2019-07-04 Updated with better pictures and Cyntech case enclosure
2019-07-04 Updated with better pictures and for Cyntech case enclosure
